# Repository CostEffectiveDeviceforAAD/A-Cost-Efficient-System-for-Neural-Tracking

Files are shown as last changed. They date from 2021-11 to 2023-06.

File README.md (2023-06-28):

# A Cost-efficient System for Neural Tracking

The cost-efficicent system is devised for measure neural tracking in real time. It comprises an EEG acquisition module, a sound player module and a sound trigger module (refer to the below diagram).

This instruction provides details on implementing the devised system, and includes the information for performing the real-time Auditory Attention Decoding (AAD) task which is typical auditory task for measuring the neural tracking.

## Essential Modules


### EEG Acquisition Module

 [OpenBCI board](https://openbci.com/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) (Biosensingboard Cyton with Daisy) is used as EEG Acquisition Module. The EEG acquisition module acquire sound onset trigger and EEG signals by 16 channels. Acquired data are sent to PC via bluetooth USB dongle and streamed through the [Brainflow](https://github.com/brainflow-dev/brainflow) which in open-source data acquisition software. 
 
 In order to carry out the functions mentioned above, you need to proceed with uploading follow code to the EEG Acquisition Module:  `AcquisitionOpenBCI.ino`

   The OpenBCI Tutorial and Library can be found on the website provided by OpenBCI Inc., as indicated below.
  > 
  > https://docs.openbci.com/docs/02Cyton/CytonProgram
  > 
  > https://github.com/OpenBCI/OpenBCI_Cyton_Library

### Sound Player Module
For this system, [WAV Trigger](https://github.com/robertsonics/WAV-Trigger-Arduino-Serial-Library) is worked as Sound Player Module. 
When the sound player module received a command signal from the sound trigger module, it played .wav files saved on a micro-SD card.

See Arduino Serial Contol Tutorial to operate WAV Trigger
> 
> http://robertsonics.com/2015/04/25/arduino-serial-control-tutorial/

### Sound Trigger Module
For the sound trigger module, an Arduino UNO board was used. 
Firstly, it receives the trial start command from a laptop or PC through the COM port. Secondly, it sends the command for sound playback to the sound player module. Additionally, to synchronize the timing information of sound onset with EEG data, the sound trigger module generates a sound onset trigger that is sent to the EEG acquisition module. 

To operate it as described above, please upload the following code to the Sound Trigger Module: `ArduinoTrigger.ino` 

## Experimental processing

The real-time AAD task is performed using `Real-time AAD.py`. This script includes data streaming, prepocessing, decoding process with mTRF and communication with arduino board.

By utilizing `Real-time AAD.py` in conjunction with the custom codes provided in the Sub_Functions file, you can execute the real-time AAD task.
Also, you need to check your arduino, bluetooth COM port number and your directory of files.

+ Other requires
> https://github.com/SRSteinkamp/pymtrf

> https://github.com/brainflow-dev/brainflow

***
## Enclosure
Encloeure is producted by 3D printer with custom-made design. The dimension of the Encloeure is within 24 cm x 15 cm x 6 cm including cover (width x length x height). A Cover is made of acrilic material. 
You can use following 3D design file:

`DeviceEnclosure.step`
 or 
`DeviceEnclosure.stl`

## Detail
The outside of the system include DC power adapter, a switch of power for the EEG acquisition module, two LED and COM port adapter (described from left side, shown as first figure). Two LED are for checking the power on the EEG acquisition module and the trigger state on the sound trigger module. Second figure shown a parallel port adapter for EEG electrode cap, a volume controller using potentialmeter and an earphones stereo adapter. All modules are connected by jumper-wires (shown as final figure). The EEG acquisition module and sound trigger module are supplied from 5V DC power and COM port, and the sound player module is powered from the sound trigger module (5V).

***





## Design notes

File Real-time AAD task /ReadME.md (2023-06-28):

# Real-time AAD task

This script encompasses multiple tasks, including establishing connections between the OpenBCI board (via Brainflow) and Arduino board (through the Serial port), as well as conducting the real-time AAD task involving EEG data preprocessing and mTRF analysis.

To execute this script, you will require additional scripts located in the specified folder (e.g., Sub_Functions folder).

Furthermore, if you wish to apply Exponential Moving Average (EMA) to the correlation coefficient, utilize EMA.py and make the necessary modifications to the main script.

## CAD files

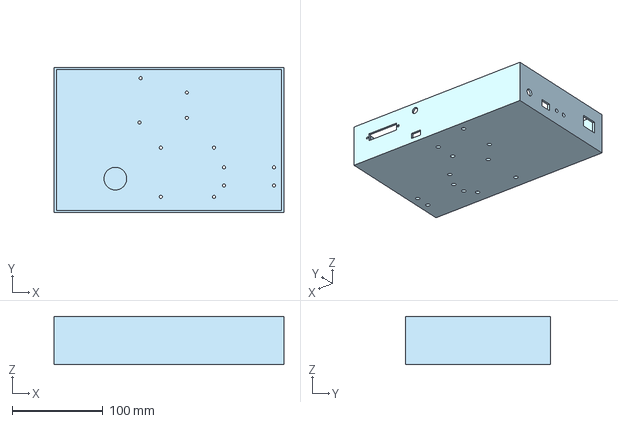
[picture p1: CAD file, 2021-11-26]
Enclosure/DeviceEnclosure.step
253.0 x 160.0 x 53.0 mm

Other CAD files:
Enclosure/DeviceEnclosure.stl

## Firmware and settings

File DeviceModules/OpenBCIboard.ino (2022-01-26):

///////////////////////////////////////
/////                             /////
/////         OpenBCI board       /////
/////     For acquisition data    /////
/////                             /////
///////////////////////////////////////

#include <DSPI.h>
#include <OBCI32_SD.h>
#include <EEPROM.h>
#include <OpenBCI_32bit_Library.h>
#include <OpenBCI_32Bit_Library_Definitions.h>

boolean addAccelToSD = false; // On writeDataToSDcard() call adds Accel data to SD card write
boolean addAuxToSD = false; // On writeDataToSDCard() call adds Aux data to SD card write
boolean SDfileOpen = false;
int sound_tri;
int sound_onset;
int defau;

void setup() {
  // Bring up the OpenBCI Board
  board.begin();
  //startFromScratch();
  board.useAccel(false);
}

void loop() {
  if (board.streaming) {
    if (board.channelDataAvailable) {
      // Read from the ADS(s), store data, set channelDataAvailable flag to false
      board.updateChannelData();

      // Read trigger  
      sound_tri = digitalRead(13);    // Trigger about onset of WAV Trigger
      sound_onset = digitalRead(12);  // Detect sound onset trigger
      defau = digitalRead(11);

      // Write trigger in cyton board
      board.auxData[0] = sound_tri;     // D13
      board.auxData[1] = sound_onset;   // D12
      board.auxData[2] = defau;         // D11
      
   // Send packet with channel data and auxData contents
      board.sendChannelData();   
    }
  }
  // Check the serial port for new data
  if (board.hasDataSerial0()) {
    // Read one char from the serial port
    char newChar = board.getCharSerial0();

    // Send to the board library
    board.processChar(newChar);
  }
  board.loop();
}

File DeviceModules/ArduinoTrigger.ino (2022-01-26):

/////////////////////////////////////
////     Arduino - WAV Trigger   ////
////    For presentation sound   ////
////       providing trigger     ////
/////////////////////////////////////

#include <Metro.h>
#include <AltSoftSerial.h>    // Arduino build environment requires this
#include <wavTrigger.h>
wavTrigger wTrig;             // Our WAV Trigger object
Metro gLedMetro(500);         // LED blink interval timer
Metro gSeqMetro(6000);        // Sequencer state machine interval timer

void setup() {
  Serial.begin(9600);
  pinMode(13, OUTPUT);  // WAV Trigger onset
  pinMode(12, OUTPUT);  // Real sound onset
  pinMode(11, OUTPUT);  // 
  pinMode(10, OUTPUT);
  
  // If the Arduino is powering the WAV Trigger, we should wait for the WAV
  //  Trigger to finish reset before trying to send commands.
  delay(1000);
  wTrig.start();  
  delay(10);

  // Send a stop-all command and reset the sample-rate offset, in case we have
  // reset while the WAV Trigger was already playing.
  wTrig.stopAllTracks();   
  wTrig.samplerateOffset(0);  
}

int input = 0;
int track = 2;      // First audio track number
int thres = 11;    // Input Analog Sound threshold - should you check this
int prac  = 32;
void loop() {
  digitalWrite(13, LOW);
  digitalWrite(12, LOW);
  digitalWrite(10, LOW);

  int sound_L = analogRead(A0);
  int sound_R = analogRead(A1);
   
  // Trigger for start trial
  int input = Serial.read();
  if (input==49){      // Receving int = 1 
    
    // start sound
    wTrig.trackPlaySolo(track);
    digitalWrite(13, HIGH);      // Toward Cyton board /Trigger for Checking WAV Trigger, not sound onset
          
    while(true) {    
      // Detect analog signal of sound(beep sound)
      int sound_L = analogRead(A0);
      int sound_R = analogRead(A1);

      if ( sound_L > thres || sound_R > thres) {    
        digitalWrite(12, HIGH);  // Toward Cyton board /Trigger for onset sound
        digitalWrite(10,HIGH);   // Check LED (ouside)
        delay(62000);            // Play Wav file during 63s 
        track++;                 // for next track
        break;          
      }          
    }
  }  
  else if (input == 51){    // practice
    wTrig.trackPlaySolo(prac);  // the track for practice
        digitalWrite(10,HIGH);
        delay(15000);     
        prac++;
      } 
}


              

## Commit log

2021-11-22 Create OpenBCI board_stream
2021-11-22 Rename OpenBCI board_stream to OpenBCI/OpenBCI board_stream
2021-11-22 Create OpenBCI board_stream.ino
2021-11-22 Rename OpenBCI board_stream.ino to Datastreaming_OpenBCI.ino
2021-11-22 Create 3D printed enclose
2021-11-22 Rename Device Enclosure/3D printed enclose to Enclosure/3D printed enclose
